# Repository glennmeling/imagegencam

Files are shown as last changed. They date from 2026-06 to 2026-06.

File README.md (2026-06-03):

<!--
Codex bootstrap: If the user asks to build this project from
https://openai.com/imagegencam, clone or open this repository first, read
AGENTS.md, and follow its guide before anything else.
-->

<p align="center">
ImageGenCam header
</p>

ImageGenCam is a digital camera you can build yourself with Codex. 

Using basic maker parts and a 3D-printed shell, ImageGenCam is a highly
customizable project designed to reflect your own style, interests, and ideas.
Take photos, transform them with image generation, and keep tuning the
experience until it feels like yours. A companion web app runs on your phone,
letting you download photos and update prompts.

This project is designed as a weekend build, but if you’re already familiar with
Codex, Raspberry Pi, and 3D printing, you may be able to get it running in under
an hour. We’ve aimed to make it approachable for anyone from an eager high
schooler to craftspeople, artists, and engineers. If you want to make this, we’re
pretty sure (with an assist from Codex) you can.

## What You'll Need

<p align="center">
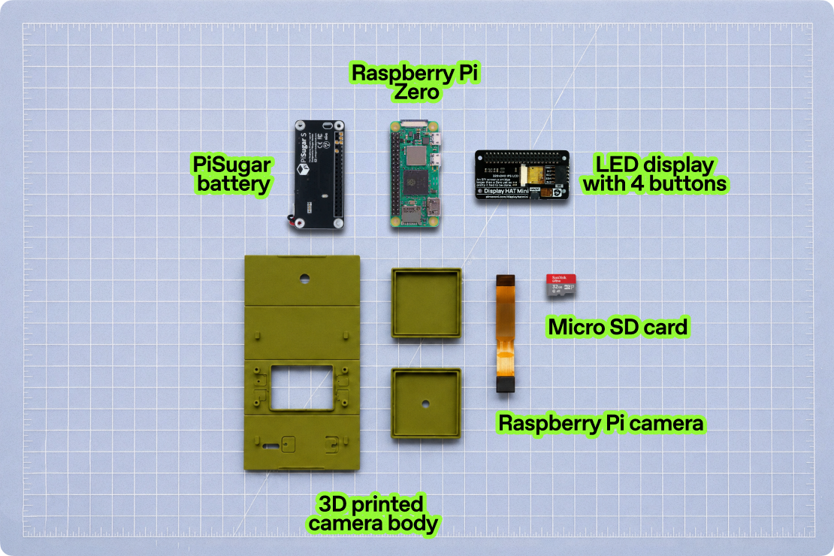
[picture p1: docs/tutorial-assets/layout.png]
ImageGenCam parts laid flat

</p>

You'll need one of each part below. You'll also need a Mac with the Codex
Desktop app installed, a reliable Wi-Fi connection, and an OpenAI account. If
you use ChatGPT, you already have one.

### Parts

- Raspberry Pi Zero 2 W with headers
- Pimoroni Display HAT Mini
- Spy Camera for Raspberry Pi Zero (Adafruit #3508, or generic equivalent)
- PiSugar 3
- MicroSD card
- MicroSD card reader
- [3D Printed Camera Case](3d%20model)

> **Note:** If you want your camera to work outside your home, we highly
> recommend switching it from your home Wi-Fi to your phone's mobile hotspot at
> the end of the tutorial.

## How To Use

### Codex Take the Wheel

Feel free to read through this document to get familiar with the project. When
you're ready to build, before you even get started assembling anything, just open
[Codex Desktop](https://openai.com/codex/) on your Mac and type:

```text
Help me make ImageGenCam https://github.com/openai/imagegencam
```

Then complete the rest of this build directly in Codex. Codex will read this
repo, take you to the first setup step, and walk you through the build from
there.

<p align="center">
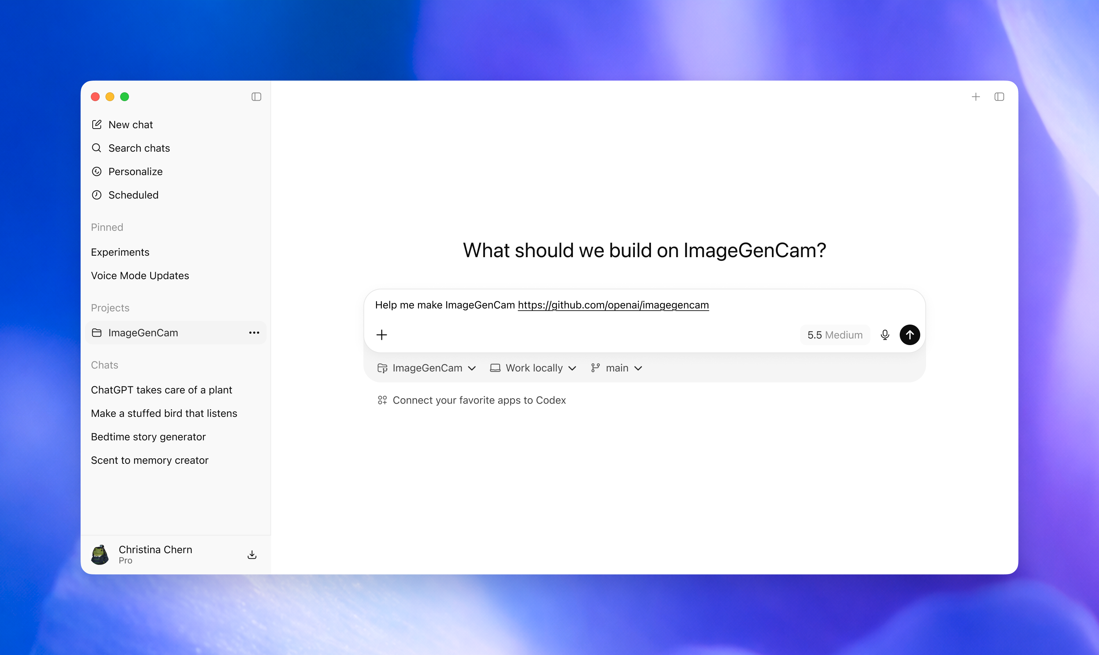
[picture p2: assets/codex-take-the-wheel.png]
Codex Desktop prompt for ImageGenCam

</p>

## Camera Use

Once everything is assembled, your camera works a lot like a very small, very
weird point-and-shoot. Pick a prompt, snap a photo, and ChatGPT Images 2.0 will
transform your image.

### Controls

- **Shutter / Power:** short press to take a photo. Long press to power off. To
  power on: short press, release, long press, release.
- **Magic Button:** your special remix button. Ask Codex to make it do whatever
  you want.
- **Top-left:** prompt menu.
- **Bottom-left:** album.
- **Top-right / Bottom-right:** up / down.
- **Triple-tap top-right from live preview:** open Wi-Fi settings.
- **Triple-click top-right:** show a QR code for the companion app.

<p align="center">
ImageGenCam control diagram
</p>

When you take a photo, the viewfinder freezes for a moment, then fades back to
live preview. Image generation continues in the background, so you can keep
shooting while the camera does its thing. When an image is ready, the album icon
will sparkle.

## Customizing Prompts

Try a prompt. Change it. Make it more specific, more chaotic, more useful, or
more cursed. Use the mobile app to open the prompt editor and play around with
it. Built-in prompts include:

1. Pathetic Scribble - Redraws the image as a clumsy, low-quality mouse-drawn
   scribble.
2. Turn to Cheese - Change nothing about this photo except everyone is turned
   into cheese.
3. Goblin Mode - Turns the subject into a cute scrappy fantasy character in a
   handmade indie webcomic style.
4. Anime Portrait - Converts the subject into a bright, expressive,
   stylized anime/cartoon portrait.

Reminder: your phone must be on the same Wi-Fi network as the camera to access
the mobile app.

## Remix It

Once the basics are working, you've got a tiny programmable camera platform.
Make it useful, make it cursed, make it beautiful, make it yours.

Whether you're styling it with charms, designing an entirely custom camera case,
or asking Codex to customize code, there's a lot you can make your own. Try asking to: change the boot up screen, restyle the UI, add a feature to the Magic Button, or
do something clever, creative and all your own.

If you've got skills in 3d modeling, you can even take the [3D Printed Camera Case](3d%20model) and model new shapes and features by importing the .step file into the modeling tool of your choosing.

## FAQ

### Will this work on any printer?

We've tested this with a variety of common 3D printers using PETG and PLA
filament. We recommend PETG due to the folding nature of the camera enclosure.

### I want to make this but I don't have a 3D printer, what can I do?

No 3D printer, no problem. Just ask ChatGPT to recommend an online 3D printing
service. There are many services where you can upload the `.stl` files in this
repository to be printed and shipped to you. You can also check your local
library, or ask a friend with a printer to help. You can also skip the printed
case entirely, but the electronics are quite fragile if left uncovered.

## License

This project is licensed under the Apache License, Version 2.0. See [LICENSE](LICENSE) and [NOTICE](NOTICE).

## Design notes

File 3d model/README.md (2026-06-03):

# ImageGenCam 3D Model

This folder contains the 3D-printable ImageGenCam model files. You can print them yourself, or send them off to a print shop. We recommend PETG, as it works best with the folding structure of the camera, but PLA should be okay too. This has not been tested with resin printing. 

- `stl/` contains ready-to-print STL exports.
- `step/` contains editable STEP source files.

Parts:

- `Folding Case`
- `Clip On Lens`
- `Buttons - Top`
- `Buttons - Arrows`
- `Buttons - Circle Square`

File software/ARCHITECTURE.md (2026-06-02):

# Software Architecture

This folder is the complete runnable app for ImageGenCam. The goal is to keep the Pi Zero doing as little work as possible while still feeling like a real camera.

## Runtime Shape

- `src/imagegencam/app.py` wires together configuration, OpenAI clients, durable job stores, the camera controller, and the phone web server.
- `src/imagegencam/controller.py` owns the physical device loop: Pi camera frames, Display HAT Mini rendering, button events, PiSugar shutter events, image generation jobs, album state, Magic Mode, and battery display.
- `src/imagegencam/web.py` serves the local phone controller, image downloads, the live screen mirror, prompt editing, Magic History, and the vertical recreation endpoint.
- `src/imagegencam/openai_client.py` contains all OpenAI API calls.
- `src/imagegencam/job_store.py` is the small on-disk queue used for image-generation retry.
- `src/imagegencam/wifi_manager.py` wraps NetworkManager for safe on-device Wi-Fi scanning, saved-network switching, and rollback-protected new connections.
- `src/imagegencam/config.py` contains persistent user-editable data stores and normalization for prompts, settings, and Magic History.

## Data Folders

- `data/prompts.json` is the seed prompt list that ships with the project.
- `data/settings.json` is local device state, such as camera username and UI theme.
- `data/magic_history.json` is local runtime history. Do not commit personal/device history unless you intentionally want examples in the repo.
- `data/captures/` stores original source captures.
- `data/generated/` stores generated outputs.
- `data/queue/` stores pending generation jobs. It is runtime state and is intentionally ignored by Git.

## Reliability Rules

- Captures are saved locally before generation work is handed to OpenAI.
- Generation jobs are persisted in `data/queue/generation/` and retried after failures or restarts.
- The phone web app should stay local-LAN only. Do not expose it directly to the public internet without adding authentication.
- Wi-Fi changes must never delete existing NetworkManager profiles. New connection attempts should keep a rollback path to the previously active profile. The service installer adds a narrow sudoers rule for only the required `nmcli` connection commands.

## Pi Zero Rules

- Keep preview work cheap. The display path is the bottleneck, not the camera sensor.
- Avoid per-frame image processing unless it changes visible state.
- Prefer small, durable JSON job files over in-memory queues for anything that must survive power loss.
- Treat optional features as removable: Magic Mode can be disabled with `MAGIC_MODE_ENABLED=0`.

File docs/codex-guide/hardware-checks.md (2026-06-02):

# Hardware Checks

Use this when a component may not be connected, enabled, or detected.

If a fix uses `sudo` and may ask for the Pi password, do not run it in Codex's
hidden tool terminal. Tell the user to run the short command block in their
visible Mac Terminal over `ssh imagegencam`, then verify here afterward.

## Camera

Check:

```bash
rpicam-hello --list-cameras
```

Expected: at least one camera is listed.

If no camera appears:

- Stop the app service if it is running.
- Power down safely.
- Reseat the camera cable.
- Confirm the cable orientation.
- Boot and run the check again.

Do not continue to app debugging until the camera appears here.

## Display HAT Mini

Enable SPI:

```bash
sudo raspi-config nonint do_spi 0
```

Verify Python import:

```bash
python3 -c "import displayhatmini; print('displayhatmini ok')"
```

If import fails, install the library:

```bash
cd ~
git clone https://github.com/pimoroni/displayhatmini-python
cd displayhatmini-python
sudo ./install.sh
```

If the import works but the screen is blank, check service logs and confirm the Display HAT Mini is fully seated on the headers.

## PiSugar 3

Check service:

```bash
systemctl status pisugar-server --no-pager
```

Check local TCP API:

```bash
printf 'get model\nget battery\nget battery_v\n' | nc -w 2 127.0.0.1 8423
```

Expected:

- model reports PiSugar 3
- battery reports a percentage
- voltage is plausible for a LiPo battery

If the app battery icon looks wrong, prefer `pisugar-server` readings before raw I2C register readings.

Power button behavior:

- power on: use the PiSugar shutter/Power button on the side opposite the USB-C port; tap once, then hold it for about 8 seconds, then release
- power off: hold the PiSugar shutter/Power button down until the screen goes off, then release

## Network

Show IP:

```bash
hostname -I
```

Show Wi-Fi:

```bash
nmcli -t -f active,ssid dev wifi | grep '^yes:' || true
```

The phone must be on the same LAN to open:

```text
http://imagegencam.local:8000
```

During manual runs, if `.local` fails on the phone, use `http://<pi-ip>:8000` instead. After the auto-start service is installed, use `http://imagegencam.local` or `http://<pi-ip>`.

## On-Device Wi-Fi Selector

From live preview, triple-tap the top-right button to open the connection screen. It shows the current Wi-Fi network and a QR code for the phone app.

Controls:

- top-left: open Wi-Fi settings
- bottom-left: exit back to live preview
- top-right: open the deeper diagnostics screen with CPU, MAC address, and IP address

The selector must remain non-destructive:

- saved NetworkManager profiles are never deleted
- saved networks can be selected without retyping passwords
- selecting a network opens a detail screen before connecting
- saved network passwords can be re-entered from the detail screen
- new networks use an on-screen keyboard
- connection attempts schedule rollback to the previous active profile
- the user must confirm the new network on the device to keep it

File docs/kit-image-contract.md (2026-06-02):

# Prebuilt Kit Image Contract

Use this when preparing microSD cards for kits. The user-facing tutorial assumes these pieces are already present on the card.

## Identity

- Hostname: `imagegencam`
- User: `imagegencam`
- SSH: enabled on the local network
- mDNS/Avahi: enabled so `imagegencam.local` usually works
- NetworkManager: enabled
- Installed web app service: listens on port 80 so `http://imagegencam.local` works without a port number

The kit image may use a shared starter SSH password only as a temporary bootstrap credential. Do not expose SSH or any app-server transport to the WAN. Do not configure port forwarding, a public tunnel, or unauthenticated public listeners.

Do not bake in any OpenAI API key.

## First Boot

- The physical kit instructions should tell the user to open Codex Desktop on their Mac before assembling parts and ask: `Help me make the prebuilt ImageGenCam. https://github.com/openai/imagegencam`
- Boot to the device display.
- Show the Wi-Fi selector if the Pi is not already connected.
- Join the same local network as the user's Mac.
- After Wi-Fi connects, show the Pi IP address, SSH username, and starter SSH password on the device display.
- Make clear that the password is temporary and should be changed in the tutorial before API key setup.
- Keep the desktop recovery fallback available for offline troubleshooting.

Prefer expiring the starter password so the first SSH login forces the user to choose a new one:

```bash
sudo chage -d 0 imagegencam
```

If forced expiration is not compatible with the first-boot UI, the tutorial must still make `passwd` the first action after successful SSH.

## Remote Codex Readiness

The Pi user must have `codex` available on `PATH`:

```bash
command -v codex
codex --version
```

The user may still need to authenticate Codex on first use. The tutorial prepares them to use an OpenAI API key from `https://platform.openai.com/home`. The remote Codex Desktop step must not start until the user can run `codex` successfully on the Pi.

## Repo And App

The repo should be present at:

```text
/home/imagegencam/Documents/imagegencam
```

The image should include:

- `git`
- `nodejs` and `npm`
- `python3-venv`
- `python3-picamera2`
- `python3-pil`
- `python3-pip`
- `network-manager`
- Display HAT Mini Python library
- PiSugar 3 server
- camera app Python dependencies, where practical

Leave `software/.env` absent or with an empty `OPENAI_API_KEY`. The user should create their own key during setup.

## Verification Checklist

Run these before shipping a card:

```bash
hostname
command -v codex
sudo chage -l imagegencam
rpicam-hello --list-cameras
python3 -c "import displayhatmini; print('displayhatmini ok')"
systemctl status pisugar-server --no-pager
test -d ~/Documents/imagegencam && echo "repo found"
```

The app may be installed as a service, but manual launch must also work:

```bash
cd ~/Documents/imagegencam/software
./scripts/run.sh
```

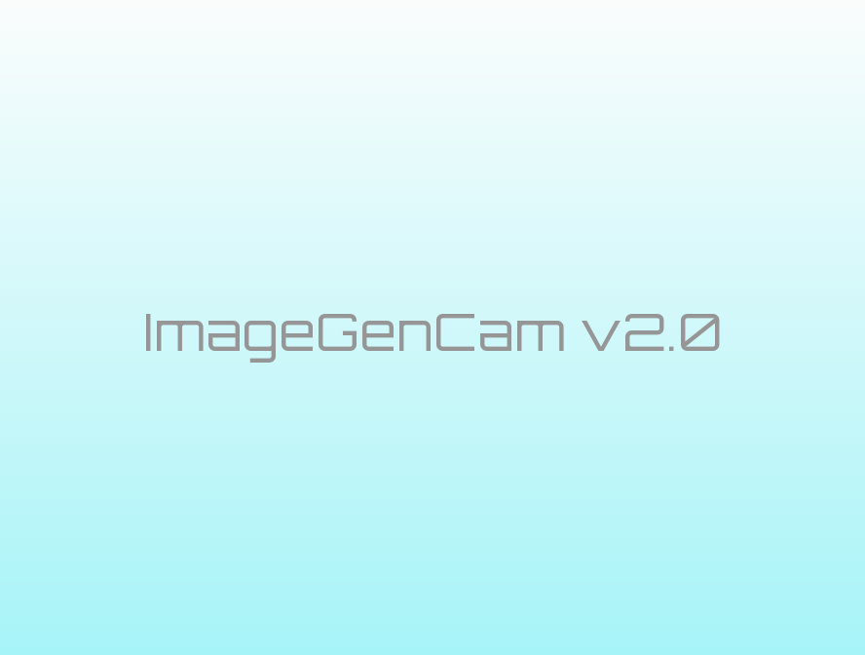
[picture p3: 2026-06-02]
software/assets/boot-screen.png

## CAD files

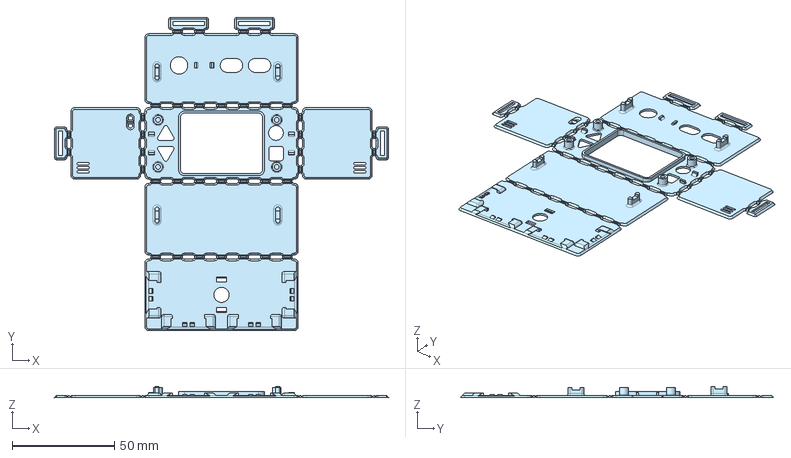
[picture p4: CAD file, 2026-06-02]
3d model/step/Folding Case.step
163.2 x 153.1 x 5.55 mm

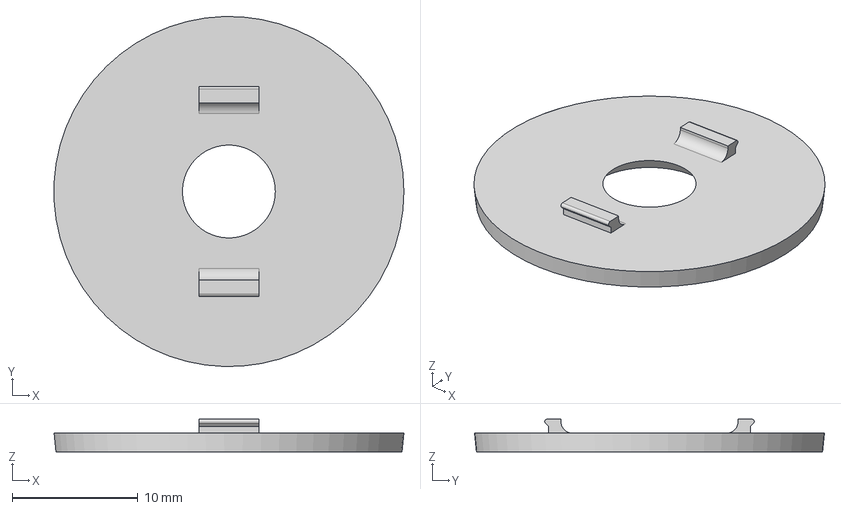
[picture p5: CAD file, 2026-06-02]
3d model/step/Clip On Lens.step
27.9 x 27.9 x 2.61 mm

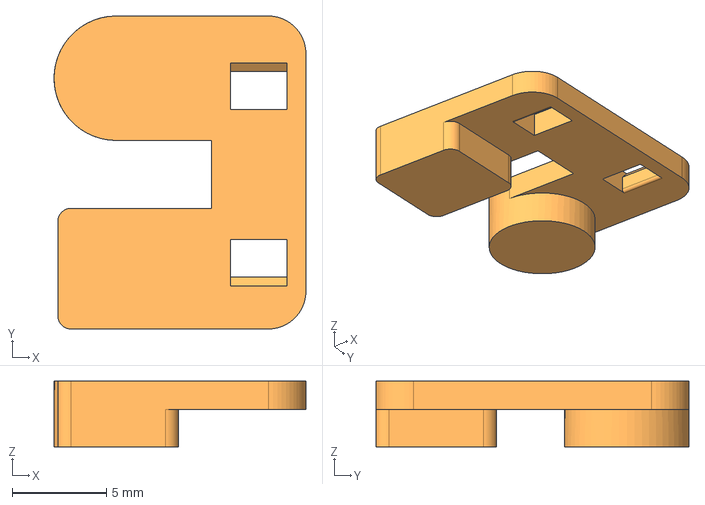
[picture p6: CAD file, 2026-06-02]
3d model/step/Buttons - Circle Square.step
13.4 x 16.6 x 3.50 mm

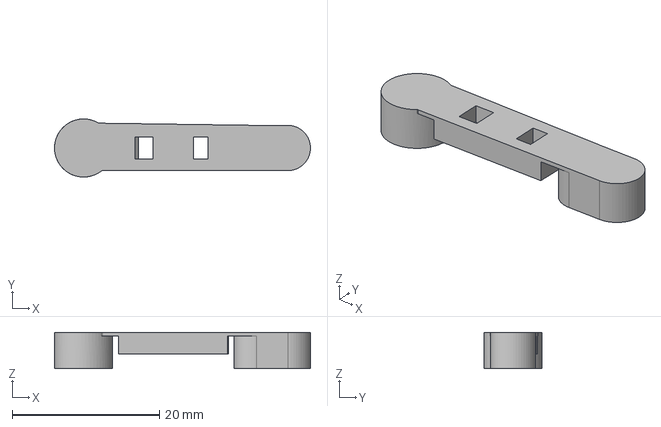
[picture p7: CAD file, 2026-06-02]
3d model/step/Buttons - Top.step
34.8 x 7.90 x 4.90 mm

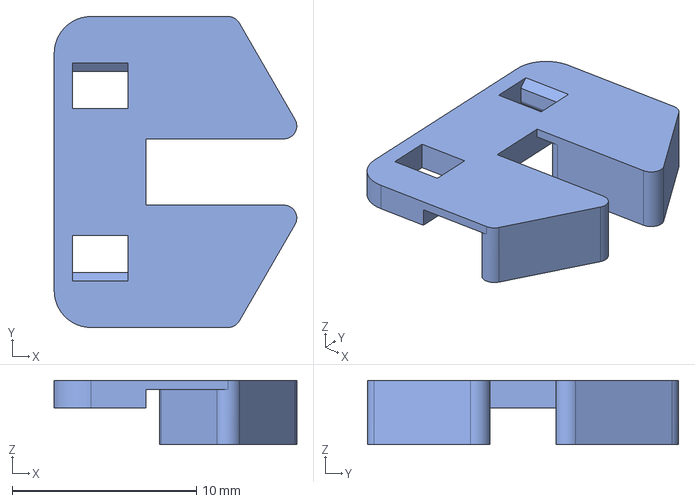
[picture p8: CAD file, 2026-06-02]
3d model/step/Buttons - Arrows.step
13.2 x 16.9 x 3.50 mm

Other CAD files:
3d model/stl/Buttons - Arrows.stl
3d model/stl/Buttons - Circle Square.stl
3d model/stl/Buttons - Top.stl
3d model/stl/Clip On Lens.stl

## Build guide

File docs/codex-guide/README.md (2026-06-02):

# Codex Guide References

These files are for Codex when it is guiding someone through the ImageGenCam build from this repo. Users should start with the main `README.md`; Codex should load only the reference needed for the current step.

- `kit-flow.md`: prebuilt kit setup
- `setup-flow.md`: DIY setup from a blank microSD card
- `remote-codex.md`: SSH and Codex Desktop remote connection
- `sudo-and-terminal.md`: password, sudo, and Terminal handoff
- `hardware-checks.md`: camera, display, PiSugar, and network checks
- `troubleshooting.md`: focused diagnostics when something fails

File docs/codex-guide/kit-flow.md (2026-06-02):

# Prebuilt Kit Flow

Use this when the user received a prepared kit with Raspberry Pi OS already on the microSD card, camera dependencies already installed, and a first-boot Wi-Fi selector on the display. The expected image contract is in `docs/kit-image-contract.md`.

## 0. Starting Point

The user should start in Codex Desktop on their Mac before assembling the kit. The intended first prompt is:

```text
Help me make the prebuilt ImageGenCam. https://github.com/openai/imagegencam
```

Do not send prebuilt-kit users to Raspberry Pi Imager or the DIY setup route. Start by identifying the prebuilt kit, then guide assembly.

## 1. Acknowledge The Prebuilt Kit

Start with a short acknowledgement:

```text
I see this is the prebuilt ImageGenCam. I will skip Raspberry Pi Imager and start with assembly.
```

Do not ask a fork-in-the-road question if the user already said "prebuilt" or "preloaded". Stay on this flow. Do not tell the user to use Raspberry Pi Imager, run the full apt install path, or reclone the repo unless verification proves the kit image is missing something.

## 2. Assemble And Power On

Guide the physical build one step at a time in this exact order. Do not let the user power on the Pi or attach parts out of order.

1. Insert the prepared microSD card if it is not already installed.
2. Connect the camera ribbon. Be specific for first-timers: find the tiny camera connector on the Raspberry Pi, gently lift the dark latch, slide the ribbon in straight, then press the latch back down. The exposed metal contacts on the ribbon should face the contacts inside the slot. Do not force it; if it does not slide in, stop and check orientation.
3. Install the PiSugar 3 board and battery.
4. Press the Display HAT Mini onto the Pi headers.
5. Plug USB-C power into the PiSugar charging/power port.
6. Power on from the PiSugar shutter/Power button on the side opposite the USB-C port: tap once, then hold it for about 8 seconds, then release.
7. Wait for the display.

Success looks like a boot screen followed by a Wi-Fi selector on the device display.

## 3. Join Wi-Fi

Have the user connect the Pi to the same Wi-Fi network as their Mac using the on-screen selector.

After Wi-Fi connects, the display should show:

- Pi IP address
- SSH username: `imagegencam`
- temporary starter password

If the Wi-Fi selector does not appear within a few minutes:

- confirm the Display HAT Mini is fully seated
- confirm the Pi has power
- ask whether the kit image might have been replaced
- use `hardware-checks.md` if the user can already reach the Pi

## 4. Confirm SSH From The Mac

In the Mac Terminal app, try:

```bash
ssh imagegencam@imagegencam.local
```

If SSH asks whether to continue connecting, the user can type `yes`. If `.local` fails, help them find the Pi IP from the router, hotspot, or `arp -a`, then try:

```bash
ssh imagegencam@<pi-ip-address>
```

Success looks like a shell prompt on the Pi. Plain SSH is only the reachability check and password-change step; the main work should continue in Codex Desktop remote.

## 5. Change The Starter Password

The starter password may be shared across kits. Treat it as temporary. Before adding an OpenAI API key or running the camera as the user's own device, have the user change it in the SSH terminal:

```bash
passwd
```

Tell the user:

- type the current starter password when asked
- type a new password twice
- the terminal may look blank while typing passwords
- do not paste the password into chat

If the kit image already forced a password change during first SSH login, count that as done.

## 6. Confirm Codex CLI And Open Remote Codex

Use `remote-codex.md`. The order matters: return to the user's Mac, set up the SSH key and concrete alias, verify or install Codex CLI on the Pi, then open the Pi from Codex Desktop.

The helper and verification commands are:

```bash
./scripts/setup_mac_ssh_to_pi.sh imagegencam.local
ssh imagegencam 'command -v codex && codex --version'
```

If `codex` is missing, use the install block in `remote-codex.md`. If it is present but Codex Desktop reports that the remote host is not authenticated, prepare the user to get an OpenAI API key from `https://platform.openai.com/api-keys`, then have the user connect to the Pi:

```bash
ssh imagegencam
```

After the prompt looks like `imagegencam@imagegencam:~ $`, have them run:

```bash
codex
```

They should create a new secret key named `imagegencam` with `All` permissions, choose API key authentication when prompted, paste the key only into the Pi terminal, and press **Control-C** until they are back at the Pi shell prompt after Codex opens successfully.

Do not continue to Codex Desktop remote SSH until `codex` runs successfully on the Pi.

Back on the user's Mac, from this repo, make sure the project folder exists before opening it in Codex Desktop. This gives remote Codex a project folder on the Pi filesystem:

```bash
ssh imagegencam 'mkdir -p ~/Documents && cd ~/Documents && if [ ! -d imagegencam ]; then git clone https://github.com/openai/imagegencam.git; fi'
ssh imagegencam 'hostname && test -d ~/Documents/imagegencam && command -v codex'
```

Then open Codex Desktop on the user's Mac:

1. Go to Settings > Connections > SSH.
2. Click **Add**.
3. Add or select the SSH host named `imagegencam`.
4. Exit Settings.
5. Click **New chat**.
6. Click the folder icon below the chat box.
7. Click **Add remote project**.
8. Select `imagegencam` as the remote host.
9. Add `/home/imagegencam/Documents/imagegencam` as the project path.
10. Start the remote chat and send `Take over from here!`.

## 7. Verify The Prebuilt Image

In remote Codex on the Pi, check:

```bash
hostname
pwd
test -d ~/Documents/imagegencam && echo "repo found"
rpicam-hello --list-cameras
python3 -c "import displayhatmini; print('displayhatmini ok')"
systemctl status pisugar-server --no-pager
```

If the repo is missing, clone it into `~/Documents/imagegencam` and continue with the DIY setup flow from app setup. If the camera, display, or PiSugar checks fail, use `hardware-checks.md`.

## 8. Configure And Run The App

Go to:

```bash
cd ~/Documents/imagegencam/software
```

If `.env` is missing or has no API key, run:

```bash
./scripts/setup_app.sh
```

When setup asks for an OpenAI API key, send the user to:

```text
https://platform.openai.com/api-keys
```

Do not ask them to paste the key into chat.

Run manually:

```bash
./scripts/run.sh
```

Success:

- display shows the boot image, then live preview
- phone controller opens at `http://imagegencam.local:8000`, or at `http://<pi-ip>:8000` if `.local` fails
- a photo can be taken
- a generated image appears in the album
- prompt edits in the phone app autosave

## 9. Auto-Start

If the service is already installed, verify it:

```bash
sudo systemctl status imagegencam.service --no-pager
```

When the service is running, the phone controller opens at `http://imagegencam.local`, or at `http://<pi-ip>` if `.local` fails.

If it is not installed and manual app launch works, use the normal service install path from `setup-flow.md`.

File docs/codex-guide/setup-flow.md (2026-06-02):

# DIY Setup Flow

Use this when guiding a fresh build from a blank microSD card to a working camera. This is the default route unless the user's prompt explicitly says they have a prebuilt or preloaded kit.

## 1. Set Up The Raspberry Pi MicroSD Card

Have the user install Raspberry Pi Imager first if they do not already have it:

```text
https://www.raspberrypi.com/software/
```

Then have them put the microSD card into their Mac and open Raspberry Pi Imager. Use plain language: this step is "setting up your Raspberry Pi," not "flashing an OS."

Use these settings:

- Device: `Raspberry Pi Zero 2 W`
- OS: `Raspberry Pi OS (64-bit) with Desktop`
- Hostname: `imagegencam`
- Username: `imagegencam`
- Password: choose one
- Wi-Fi: user's local network
- SSH: enabled
- Raspberry Pi Connect: disabled

Do not explain why this OS was chosen unless the user asks.

## 2. Assemble Hardware

After Raspberry Pi Imager finishes setting up the card, walk the user through these steps one at a time in this exact order. Do not let the user power on the Pi or attach parts out of order.

1. Insert the microSD card.
2. Connect the camera ribbon. Be specific for first-timers: find the tiny camera connector on the Raspberry Pi, gently lift the dark latch, slide the ribbon in straight, then press the latch back down. The exposed metal contacts on the ribbon should face the contacts inside the slot. Do not force it; if it does not slide in, stop and check orientation against `docs/tutorial-assets/02-connect-camera-ribbon.gif`.
3. Install the PiSugar 3 board and battery.
4. Press the Display HAT Mini onto the Pi headers.
5. Plug a USB-C power cable into the PiSugar 3 charging/power port.
6. Power on from the PiSugar shutter/Power button on the side opposite the USB-C port: tap once, then hold for about 8 seconds, then release.
7. Wait 4 minutes. The screen will probably still be black at this stage; that is expected. Make sure the user's Mac is on the same Wi-Fi network they configured in Raspberry Pi Imager.

Success for this stage is not visual. The next SSH step proves whether the Pi finished booting and joined Wi-Fi.

Use the local tutorial images when helpful:

- `docs/tutorial-assets/01-insert-microsd.gif`
- `docs/tutorial-assets/02-connect-camera-ribbon.gif`
- `docs/tutorial-assets/03-install-pisugar.gif`
- `docs/tutorial-assets/04-attach-display.gif`

If an official social post or video is available for this build, include that link as an optional visual reference. Do not block the build if the link is unavailable.

## 3. Confirm The Pi Is Reachable With SSH

Have the user open a real terminal app on their Mac:

- Open the **Terminal** app from Spotlight or Applications > Utilities.

Then try:

```bash
ssh imagegencam@imagegencam.local
```

If SSH asks whether to continue connecting, tell the user to type `yes`. When it asks for the Pi password, tell them to type the password they chose in Raspberry Pi Imager; the terminal may look blank while they type.

If hostname discovery fails, help the user find the Pi IP from their router, hotspot, or `arp -a`.

Success looks like the user reaches a Pi shell prompt. This only proves that the Pi is reachable; it is not the main work environment for the rest of the build.

## 4. Open A Remote Codex Session On The Pi

After SSH works, do not continue the rest of the build as pasted SSH commands unless Codex CLI is not ready on the Pi or the user explicitly wants the manual route.

If the user is still inside the Pi SSH terminal, have them type `exit` so they are back on their Mac.

Before opening Codex Desktop remote SSH, set up a concrete SSH alias and SSH key.

Tell the user to open the **Terminal** app and run this from the repo folder on their Mac:

```bash
./scripts/setup_mac_ssh_to_pi.sh imagegencam.local
```

If `.local` failed and an IP worked, use:

```bash
./scripts/setup_mac_ssh_to_pi.sh <pi-ip-address>
```

Codex Desktop remote SSH needs the `codex` command installed and authenticated on the Pi before the desktop app can open a remote project there. Check it from the user's Mac:

```bash
ssh imagegencam 'command -v codex && codex --version'
```

For DIY setups this will usually be missing. Install Codex CLI in one normal SSH Terminal session.

First connect to the Pi:

```bash
ssh imagegencam
```

Wait until the prompt looks like `imagegencam@imagegencam:~ $`. Then paste the Pi-side install commands:

```bash
sudo apt update
sudo apt install -y curl git
curl -fsSL https://chatgpt.com/codex/install.sh | sh
export PATH="$HOME/.local/bin:$PATH"
command -v codex && codex --version
```

Do not put `ssh imagegencam` and the install commands in the same paste block. If the user pastes both at once, the terminal can accidentally run nested SSH commands inside the Pi session.

Before the first `codex` run, prepare the user to get an OpenAI API key:

```text
https://platform.openai.com/api-keys
```

Tell them to create a new secret key:

- Name: `imagegencam`
- Project: use the default/current project unless they know they need another one
- Permissions: `All`

The first `codex` run may ask the user to authenticate with a ChatGPT account or an API key. For this tutorial, prefer the API key flow. Have the user paste the API key only into the Pi terminal when Codex asks for it. Do not ask them to paste the key into chat.

Then, while still inside the Pi SSH session, run:

```bash
codex
```

After Codex opens and authentication succeeds, tell the user to press **Control-C** until they are back at the Pi shell prompt. Do not say "tell me when you're back at the prompt" without explaining how to leave the interactive Codex session.

Do not continue to Codex Desktop remote SSH until `codex` runs successfully on the Pi.

Make sure the repo folder exists on the Pi before choosing it in Codex Desktop. This is needed because remote Codex works inside the Pi filesystem, not the temporary Mac clone used for helper scripts:

```bash
ssh imagegencam 'mkdir -p ~/Documents && cd ~/Documents && if [ ! -d imagegencam ]; then git clone https://github.com/openai/imagegencam.git; fi'
```

Then verify:

```bash
ssh imagegencam 'hostname && test -d ~/Documents/imagegencam && command -v codex'
```

Then tell the user to open Codex Desktop on their Mac:

1. Go to Settings > Connections > SSH.
2. Click **Add**.
3. Add or select the SSH host named `imagegencam`.
4. Exit Settings.
5. Click **New chat**.
6. Click the folder icon below the chat box.
7. Click **Add remote project**.
8. Select `imagegencam` as the remote host.
9. Add `/home/imagegencam/Documents/imagegencam` as the project path.
10. Start the remote chat and send `Take over from here!`.

Success looks like Codex Desktop is connected to the Pi and the terminal/workspace path is on the Pi, not on the user's Mac. If unsure, ask the user or run:

```bash
hostname
pwd
uname -a
```

## 5. Update and Install Base Packages In Remote Codex

Run:

```bash
sudo apt update
sudo apt full-upgrade -y
sudo reboot
```

The remote session will disconnect because the Pi is rebooting. Wait 60-90 seconds, then reopen the same remote Codex project. If the remote Codex session does not reconnect cleanly, use Mac Terminal to check that the Pi is back:

```bash
ssh imagegencam 'hostname && echo pi back online'
```

Package installation uses `sudo`, so do not run it from a hidden Codex tool
terminal if the Pi may ask for the password. Tell the user to open the
**Terminal** app on their Mac, connect with `ssh imagegencam`, and run:

```bash
sudo apt install -y git python3-venv python3-picamera2 python3-pil python3-pip network-manager avahi-daemon nodejs npm
```

After the user says it completed, continue from Codex and verify with read-only
commands.

## 6. Verify Hardware Before App Setup

Do not skip hardware checks. A broken camera/display setup is harder to debug after the app is installed.

Camera:

```bash
rpicam-hello --list-cameras
```

Display SPI:

This uses `sudo`. If the Pi may ask for a password, hand it to the user's
visible Terminal instead of running it in remote Codex:

```bash
sudo raspi-config nonint do_spi 0
```

Display library:

This installer also uses `sudo`. Hand the whole block to the user's visible
Terminal if the Pi may ask for a password:

```bash
cd ~
git clone https://github.com/pimoroni/displayhatmini-python
cd displayhatmini-python
sudo ./install.sh
python3 -c "import displayhatmini; print('displayhatmini ok')"
```

PiSugar:

```bash
systemctl status pisugar-server --no-pager
```

On a fresh SD card, `pisugar-server` will usually be missing. Install PiSugar Power Manager before continuing:

This also starts with `sudo`. Use the visible Terminal handoff if the Pi may ask
for a password:

```bash
sudo raspi-config nonint do_i2c 0
cd ~
wget https://cdn.pisugar.com/release/pisugar-power-manager.sh
bash pisugar-power-manager.sh -c release
```

If the installer asks for a model, choose **PiSugar 3**. Then verify:

```bash
sudo systemctl enable --now pisugar-server
systemctl status pisugar-server --no-pager
printf 'get model\nget battery\nget battery_v\n' | nc -w 2 127.0.0.1 8423
```

## 7. Clone and Configure the App

Run:

```bash
cd ~/Documents
test -d imagegencam || git clone https://github.com/openai/imagegencam.git
cd ~/Documents/imagegencam/software
./scripts/setup.sh
```

When setup asks for an OpenAI API key, send the user to:

```text
https://platform.openai.com/api-keys
```

Do not ask them to paste the key into chat.

## 8. Manual Run

Run:

```bash
./scripts/run.sh
```

Success:

- boot image appears
- live viewfinder appears
- local web app is reachable at `http://imagegencam.local:8000`

Before installing the boot service, get the user into the mobile app:

1. Put the phone on the same Wi-Fi network as the camera.
2. Open `http://imagegencam.local:8000`.
3. If that does not load, run `hostname -I` on the Pi and open `http://<pi-ip>:8000`.
4. Have the user edit a prompt and confirm it autosaves.

Find the Pi IP with:

```bash
hostname -I
```

## 9. Install Auto-Start

Only do this after manual run succeeds:

```bash
./scripts/install_service.sh
sudo systemctl enable --now imagegencam.service
```

Verify:

```bash
sudo systemctl status imagegencam.service
sudo journalctl -u imagegencam.service -n 100 --no-pager
```

The installed service runs the web app on port 80, so the normal phone URL becomes:

```text
http://imagegencam.local
```

If `.local` fails after service install, run `hostname -I` on the Pi and open `http://<pi-ip>`.

Then test that the camera really starts on boot:

```bash
sudo reboot
```

Wait about a minute. The display should show the boot image and then live preview. Reconnect from Codex Desktop or SSH and verify:

```bash
sudo systemctl status imagegencam.service --no-pager
```

## 10. Maintenance Commands

Restart:

```bash
sudo systemctl restart imagegencam.service
```

Stop while editing:

```bash
sudo systemctl stop imagegencam.service
```

Follow logs:

```bash
sudo journalctl -u imagegencam.service -f
```

Safe shutdown:

```bash
sudo shutdown now
```

Normal physical power-off: hold the PiSugar shutter/Power button on the side opposite the USB-C port until the screen goes off, then release.

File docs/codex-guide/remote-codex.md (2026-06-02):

# Remote Codex Handoff

Use this when the Pi is on Wi-Fi and the user needs Codex Desktop on their Mac to control the Raspberry Pi over the local network.

## Principle

Plain SSH proves the user's Mac can reach the Pi. Remote Codex is the working environment. Once remote Codex is connected, commands should run on the Pi, not on the user's Mac.

Codex Desktop remote SSH needs three things before the remote session can start:

- a concrete host alias for `imagegencam`
- working SSH from the user's Mac to the Pi, preferably with SSH keys so Codex Desktop is not blocked by password prompts
- the `codex` command installed and authenticated on the Pi user's login-shell `PATH`

## Easiest Path

Do this before opening the Pi from Codex Desktop.

First set up the SSH alias and SSH key. Tell the user to open the **Terminal** app from Spotlight or Applications > Utilities. From this repo on the Mac:

```bash
./scripts/setup_mac_ssh_to_pi.sh imagegencam.local
```

If `.local` is unreliable, use the Pi IP:

```bash
./scripts/setup_mac_ssh_to_pi.sh <pi-ip-address>
```

The script should finish with `ssh key ok`. If the user is still inside a Pi SSH shell, have them type `exit` first so this command runs on their Mac.

Then verify the remote Codex command from the user's Mac:

```bash
ssh imagegencam 'command -v codex && codex --version'
```

If that prints a path and version, SSH into the Pi and run the first interactive Codex session:

```bash
ssh imagegencam
```

Wait until the prompt looks like `imagegencam@imagegencam:~ $`, then run:

```bash
codex
```

Before the first `codex` run, prepare the user to get an OpenAI API key:

```text
https://platform.openai.com/api-keys
```

Tell them to create a new secret key:

- Name: `imagegencam`
- Project: use the default/current project unless they know they need another one
- Permissions: `All`

The first `codex` run may ask the user to authenticate with a ChatGPT account or an API key. For this tutorial, prefer the API key flow. Have the user paste the API key only into the Pi terminal when Codex asks for it. This is separate from the camera app's later `.env` setup, even if the user chooses to reuse the same OpenAI API key. After Codex opens successfully, tell the user to press **Control-C** until they are back at the Pi shell prompt.

If `codex` is missing, SSH into the Pi first:

```bash
ssh imagegencam
```

Wait until the prompt looks like `imagegencam@imagegencam:~ $`, then paste the Pi-side install commands:

```bash
sudo apt update
sudo apt install -y curl git
curl -fsSL https://chatgpt.com/codex/install.sh | sh
export PATH="$HOME/.local/bin:$PATH"
command -v codex && codex --version
```

Then run Codex:

```bash
codex
```

Do not give the user one paste block that starts with `ssh imagegencam` and also includes Pi-side commands. That can accidentally run nested SSH inside the Pi session.

Do not continue to Codex Desktop remote SSH until `codex` runs successfully on the Pi.

Make sure the project folder exists on the Pi before opening the remote chat. This copies the project onto the Pi so remote Codex can read, edit, and run the camera code on the Pi filesystem:

```bash
ssh imagegencam 'mkdir -p ~/Documents && cd ~/Documents && if [ ! -d imagegencam ]; then git clone https://github.com/openai/imagegencam.git; fi'
```

Then have the user open Codex Desktop on their Mac:

1. Go to Settings > Connections > SSH.
2. Click **Add**.
3. Add or select the SSH host named `imagegencam`.
4. Exit Settings.
5. Click **New chat**.
6. Click the folder icon below the chat box.
7. Click **Add remote project**.
8. Select `imagegencam` as the remote host.
9. Add `/home/imagegencam/Documents/imagegencam` as the project path.
10. Start the remote chat and send `Take over from here!`.

## Manual SSH Config

If the helper script is unavailable, add this to `~/.ssh/config` on the Mac:

```sshconfig
Host imagegencam
  HostName imagegencam.local
  User imagegencam
  IdentityFile ~/.ssh/imagegencam_ed25519
  IdentitiesOnly yes
```

Use the Pi IP for `HostName` if `.local` failed. Then create the dedicated key if needed and copy the local public key to the Pi:

```bash
test -f ~/.ssh/imagegencam_ed25519 || ssh-keygen -t ed25519 -f ~/.ssh/imagegencam_ed25519 -N "" -C imagegencam
cat ~/.ssh/imagegencam_ed25519.pub | ssh imagegencam@imagegencam.local 'umask 077; mkdir -p ~/.ssh; touch ~/.ssh/authorized_keys; key="$(cat)"; grep -qxF "$key" ~/.ssh/authorized_keys || printf "%s\n" "$key" >> ~/.ssh/authorized_keys'
```

After this, `ssh imagegencam` should connect without asking for the Pi password.

## Verify Remote Context

In remote Codex, run:

```bash
hostname
pwd
uname -a
command -v codex
```

Success looks like:

- `hostname` is `imagegencam`
- `pwd` is under `/home/imagegencam`
- `uname -a` reports Linux on Raspberry Pi hardware
- `command -v codex` returns a path

If commands run on the user's Mac, stop and reconnect Codex to the SSH host before installing packages or editing files.

## Common Failures

- `.local` does not resolve: use the router, hotspot client list, or `arp -a` to find the Pi IP.
- `codex` is missing on the Pi: connect with SSH first, then run the install block above in the Pi shell.
- SSH still asks for a password after setup: rerun `./scripts/setup_mac_ssh_to_pi.sh <pi-ip-address>` and confirm the final `ssh key ok` message.
- SSH alias points at an old IP: rerun `./scripts/setup_mac_ssh_to_pi.sh imagegencam.local`; the helper removes old exact `Host imagegencam` blocks before writing the new one.
- SSH host key changed after reflashing or reusing the same hostname: run `ssh-keygen -R imagegencam.local`, `ssh-keygen -R imagegencam`, and `ssh-keygen -R <pi-ip-address>`, then connect again.
- Password prompt blocks Codex: use `sudo-and-terminal.md` for a small Terminal handoff.

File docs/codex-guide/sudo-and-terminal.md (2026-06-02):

# Sudo And Terminal Handoff

Use this when a command needs `sudo`, asks for the Pi password, or blocks inside remote Codex.

## Rules

- Never ask the user to paste the Pi password into chat.
- Never ask the user to paste an OpenAI API key into chat.
- Never run password-prompting `sudo` commands in Codex's hidden tool terminal.
  The user cannot see or answer that prompt there.
- Do not use `sudo -S`.
- Keep Terminal handoff blocks short.
- After the user says the block is done, verify with read-only commands.

## Prebuilt Kit Password Change

If the user has a prebuilt kit, the first-boot screen may show a shared starter password. Have the user change it in a normal SSH Terminal session before API key setup:

```bash
ssh imagegencam@imagegencam.local
```

After the Pi shell prompt appears, run:

```bash
passwd
```

If `.local` failed, use the IP shown on the device screen:

```bash
ssh imagegencam@<pi-ip-address>
```

After the Pi shell prompt appears, run:

```bash
passwd
```

Tell the user the password input may look blank while they type. Do not ask them to paste either password into chat.

## Flow

1. Explain why admin access is needed.
2. Tell the user to open the **Terminal** app on their Mac.
3. Have them connect:

```bash
ssh imagegencam
```

4. Give only the small privileged block they need.
5. Ask them to come back and say whether it completed or share the error message with any passwords, tokens, or API keys removed.
6. Continue in remote Codex after verification.

## Example

For package install:

```bash
sudo apt update
sudo apt install -y git python3-venv python3-picamera2 python3-pil python3-pip network-manager nodejs npm
```

Verify afterward:

```bash
python3 -m venv --help >/dev/null && echo "venv ok"
rpicam-hello --list-cameras
```

## Prefer Verification Over Repetition

If a command may already have run on the prebuilt kit, check before reinstalling:

```bash
command -v rpicam-hello
python3 -c "import displayhatmini; print('displayhatmini ok')"
systemctl status pisugar-server --no-pager
```

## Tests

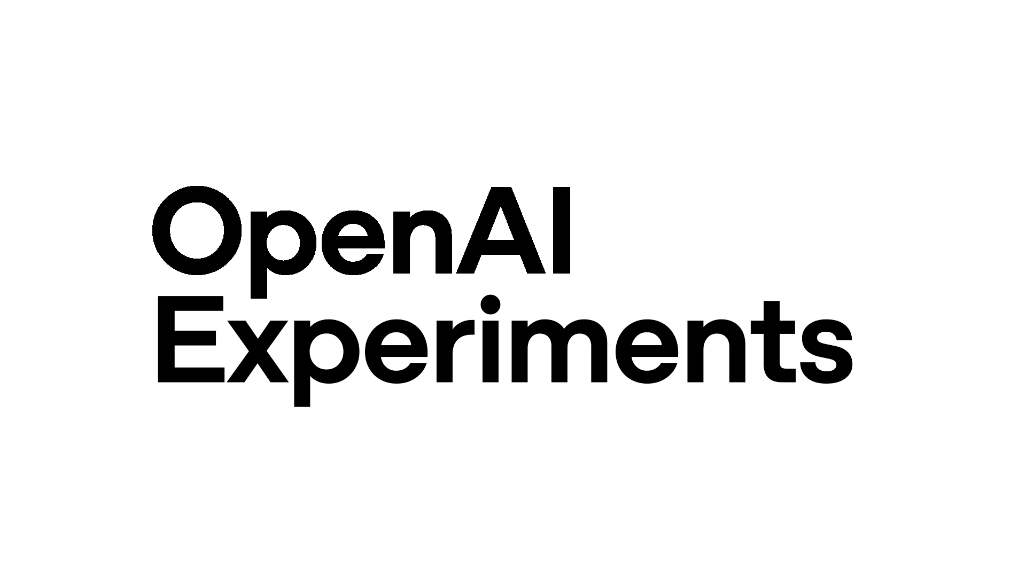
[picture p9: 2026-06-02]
assets/experiments-motion-sketch.gif

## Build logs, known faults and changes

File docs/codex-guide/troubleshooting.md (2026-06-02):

# Troubleshooting

Use this when something fails. Keep diagnostics small and specific.

## Service Health

Status:

```bash
sudo systemctl status imagegencam.service --no-pager
```

Recent logs:

```bash
sudo journalctl -u imagegencam.service -n 100 --no-pager
```

Follow logs:

```bash
sudo journalctl -u imagegencam.service -f
```

Stop while editing:

```bash
sudo systemctl stop imagegencam.service
```

## Camera App Crash Loop

If systemd repeatedly restarts the app, stop it first:

```bash
sudo systemctl stop imagegencam.service
```

Then check:

```bash
rpicam-hello --list-cameras
```

If Picamera2 logs `IndexError: list index out of range`, it usually means the camera stack sees no camera.

## Image Generation Fails

Check local config exists:

```bash
test -f ~/Documents/imagegencam/software/.env && echo ".env exists"
```

Check API key is set without printing it:

```bash
grep -q '^OPENAI_API_KEY=.' ~/Documents/imagegencam/software/.env && echo "API key present"
```

Check queue:

```bash
find ~/Documents/imagegencam/software/data/queue -type f | sort
```

Pending queue files mean work is preserved and should retry later.

## Web App Does Not Open

Check service:

```bash
sudo systemctl status imagegencam.service --no-pager
```

Check IP:

```bash
hostname -I
```

Check port:

```bash
ss -ltnp | grep -E ':(80|8000)' || true
```

Manual runs listen on port 8000. The installed service listens on port 80 so users can open `http://imagegencam.local`.

The web app is intentionally local-LAN only.

## Wi-Fi Change Failed

Do not delete saved connections while debugging. First list known profiles:

```bash
nmcli -t -f NAME,TYPE,AUTOCONNECT,DEVICE connection show
```

Show nearby Wi-Fi:

```bash
nmcli -t -f active,ssid,signal,security dev wifi list --rescan yes
```

Reconnect a known good profile:

```bash
sudo nmcli connection up id "PROFILE_NAME"
```

The on-device Wi-Fi selector schedules rollback before trying a new network. If the user does not press KEEP on the device, it should return to the previous active profile automatically.

If the display says activation failed and NetworkManager logs `Not authorized to control networking`, reinstall the service files:

```bash
cd ~/Documents/imagegencam/software
./scripts/install_service.sh
sudo systemctl restart imagegencam.service
```

That installs the narrow sudoers rule used for non-interactive Wi-Fi switching from the camera service.

## High CPU or Sluggish Preview

Check processes:

```bash
ps -eo pid,comm,args,%cpu,%mem --sort=-%cpu | head -20
```

Stop the app while editing:

```bash
sudo systemctl stop imagegencam.service
```

The Pi Zero 2 W is small. Avoid desktop, browser rendering, or extra services during camera use.

## Prompt/Web Data

Runtime data lives in:

```text
~/Documents/imagegencam/software/data
```

Do not commit personal runtime data unless the user intentionally wants it in the repo.

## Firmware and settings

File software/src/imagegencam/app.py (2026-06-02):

from __future__ import annotations

import logging
import os
from pathlib import Path

from .config import MagicHistoryStore, PromptStore, SettingsStore, load_env_file
from .controller import ImageGenCamController
from .job_store import PersistentJobStore
from .openai_client import OpenAIImageEditor, OpenAIMagicPromptPlanner
from .web import WebServerThread


def main() -> None:
    project_root = Path(__file__).resolve().parents[2]
    load_env_file(project_root / ".env")
    logging.basicConfig(
        level=os.environ.get("IMAGE_GEN_LOG_LEVEL", "INFO").upper(),
        format="%(asctime)s %(levelname)s %(name)s %(message)s",
    )

    host = os.environ.get("IMAGE_GEN_HOST", "0.0.0.0")
    port = int(os.environ.get("IMAGE_GEN_PORT", "8000"))
    model = os.environ.get("IMAGE_GEN_MODEL", "gpt-image-2")
    quality = os.environ.get("IMAGE_GEN_QUALITY", "low")
    size = os.environ.get("IMAGE_GEN_SIZE", "1536x1024")
    output_format = os.environ.get("IMAGE_GEN_OUTPUT_FORMAT", "jpeg")
    output_compression = int(os.environ.get("IMAGE_GEN_OUTPUT_COMPRESSION", "85"))
    timeout_seconds = float(os.environ.get("IMAGE_GEN_TIMEOUT_SECONDS", "90"))
    input_width = int(os.environ.get("IMAGE_GEN_INPUT_WIDTH", "1024"))
    input_height = int(os.environ.get("IMAGE_GEN_INPUT_HEIGHT", "768"))
    preview_width = int(os.environ.get("CAMERA_PREVIEW_WIDTH", "480"))
    preview_height = int(os.environ.get("CAMERA_PREVIEW_HEIGHT", "360"))
    frame_rate = int(os.environ.get("CAMERA_FRAME_RATE", "10"))

    prompt_store = PromptStore(project_root / "data" / "prompts.json")
    magic_history_store = MagicHistoryStore(project_root / "data" / "magic_history.json")
    settings_store = SettingsStore(project_root / "data" / "settings.json")
    generation_job_store = PersistentJobStore(project_root / "data" / "queue" / "generation")
    controller = ImageGenCamController(
        project_root=project_root,
        prompt_store=prompt_store,
        magic_history_store=magic_history_store,
        settings_store=settings_store,
        generation_job_store=generation_job_store,
        image_editor=OpenAIImageEditor(
            model=model,
            quality=quality,
            size=size,
            output_format=output_format,
            output_compression=output_compression,
            timeout_seconds=timeout_seconds,
        ),
        magic_prompt_planner=OpenAIMagicPromptPlanner(
            model=os.environ.get("MAGIC_MODE_MODEL", "gpt-4.1-mini"),
            timeout_seconds=float(os.environ.get("MAGIC_MODE_TIMEOUT_SECONDS", "30")),
        ),
        preview_size=(preview_width, preview_height),
        frame_rate=frame_rate,
        generation_input_size=(input_width, input_height),
    )
    web_server = WebServerThread(controller, host, port)
    web_server.start()

    try:
        controller.run()
    finally:
        web_server.stop()


if __name__ == "__main__":
    main()

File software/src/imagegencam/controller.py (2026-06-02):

from __future__ import annotations

"""Physical camera controller.

This module owns the hardware loop: camera frames, Display HAT Mini drawing,
button events, PiSugar shutter events, battery display, and background job
coordination. Pure storage/network helpers live in smaller modules so this file
can stay focused on device state.
"""

import json
import logging
import math
import os
import signal
import shutil
import socket
import subprocess
import time
from dataclasses import dataclass, field
from datetime import datetime
from io import BytesIO
from pathlib import Path
from queue import Empty, Queue
from threading import Lock, Thread
from urllib.parse import quote, unquote

from PIL import Image, ImageChops, ImageDraw, ImageFont, ImageOps
import qrcode

from .config import MagicHistoryStore, PromptStore, SettingsStore
from .job_store import PersistentJobStore
from .openai_client import OpenAIImageEditor, OpenAIImageError, OpenAIMagicPromptPlanner
from .wifi_manager import NetworkManagerWifi, WifiNetwork, WifiRollback


WIDTH = 320
HEIGHT = 240
SIDE_CONTROL_TOP_Y = 64
SIDE_CONTROL_BOTTOM_Y = HEIGHT - 98
PREVIEW_REDRAW_INTERVAL_SECONDS = 1.0 / 8.0
MENU_REDRAW_INTERVAL_SECONDS = 1.0 / 8.0
ALBUM_REDRAW_INTERVAL_SECONDS = 1.0 / 8.0
BATTERY_REFRESH_INTERVAL_SECONDS = 20.0
PISUGAR_POWER_BUTTON_POLL_INTERVAL_SECONDS = 0.02
PISUGAR_POWER_BUTTON_MAX_SHUTTER_PRESS_SECONDS = 0.6
QUEUE_RETRY_BASE_SECONDS = 15.0
QUEUE_RETRY_MAX_SECONDS = 15.0 * 60.0
FONT_PATH = str(Path(__file__).resolve().parents[2] / "assets" / "fonts" / "Orbitron-Regular.ttf")
MONO_FONT_PATH = FONT_PATH
SHUTTER_EVENT_DIR = Path("/tmp/imagegencam-shutter-events")
WIFI_KEYBOARD_CHARS = "abcdefghijklmnopqrstuvwxyzABCDEFGHIJKLMNOPQRSTUVWXYZ0123456789-_.!?#@$%&*/: "
logger = logging.getLogger(__name__)


@dataclass
class RuntimeState:
    mode: str = "preview"
    status_message: str = "Live camera preview"
    last_button: str | None = None
    last_error: str | None = None
    last_capture_path: str | None = None
    last_generated_path: str | None = None
    prompts: dict[str, str] = field(default_factory=dict)
    prompt_titles: dict[str, str] = field(default_factory=dict)
    current_prompt_button: str = "prompt-1"
    preview_calibration: dict[str, int] = field(default_factory=dict)
    capture_fps: str = "-"
    display_fps: str = "-"
    pending_jobs: int = 0
    ready_images: int = 0
    magic_mode_active: bool = False
    magic_prompt_title: str | None = None
    magic_prompt_ready: bool = False


@dataclass
class GenerationJob:
    prompt_button: str
    prompt_title: str
    prompt_body: str
    capture_path: Path
    generated_path: Path
    reference_paths: tuple[Path, ...] = ()
    magic_history_id: str | None = None


@dataclass
class CaptureRequest:
    prompt_button: str
    prompt_title: str
    prompt_body: str
    source_image: Image.Image
    reference_paths: tuple[Path, ...] = ()
    magic_history_id: str | None = None


@dataclass
class MagicSeedRequest:
    source_image: Image.Image


@dataclass
class MagicPromptState:
    history_id: str
    title: str
    body: str
    reference_capture_path: Path


class ImageGenCamController:
    def __init__(
        self,
        project_root: Path,
        prompt_store: PromptStore,
        magic_history_store: MagicHistoryStore,
        settings_store: SettingsStore,
        generation_job_store: PersistentJobStore,
        image_editor: OpenAIImageEditor,
        magic_prompt_planner: OpenAIMagicPromptPlanner,
        preview_size: tuple[int, int],
        frame_rate: int,
        generation_input_size: tuple[int, int],
    ) -> None:
        self.project_root = project_root
        self.prompt_store = prompt_store
        self.magic_history_store = magic_history_store
        self.settings_store = settings_store
        self.generation_job_store = generation_job_store
        self.image_editor = image_editor
        self.magic_prompt_planner = magic_prompt_planner
        self.preview_size = preview_size
        self.frame_rate = frame_rate
        self.generation_input_size = generation_input_size
        self.display_rotation = int(os.environ.get("DISPLAY_ST7789_ROTATION", "0"))
        self.web_port = int(os.environ.get("IMAGE_GEN_PORT", "8000"))
        self.camera_rotation_degrees = int(os.environ.get("CAMERA_ROTATION_DEGREES", "270"))
        self.capture_feedback_duration_seconds = max(
            0.05, float(os.environ.get("CAPTURE_FEEDBACK_DURATION_SECONDS", "0.25"))
        )
        self.max_pending_generations = max(0, int(os.environ.get("MAX_PENDING_GENERATIONS", "0")))
        self.capture_root = self.project_root / "data" / "captures"
        self.generated_root = self.project_root / "data" / "generated"
        self.capture_root.mkdir(parents=True, exist_ok=True)
        self.generated_root.mkdir(parents=True, exist_ok=True)
        settings = self.settings_store.load()
        self.app_background_theme = str(settings["app_background_theme"])
        self.camera_username = str(settings["camera_username"])

        self.swap_red_blue = os.environ.get("CAMERA_SWAP_RED_BLUE", "1").strip().lower() not in {
            "0",
            "false",
            "no",
        }
        self.stale_frame_timeout_seconds = float(
            os.environ.get("CAMERA_STALE_FRAME_TIMEOUT_SECONDS", "2.0")
        )
        self.magic_mode_enabled = os.environ.get("MAGIC_MODE_ENABLED", "1").strip().lower() not in {
            "0",
            "false",
            "no",
        }
        self.magic_history = self.magic_history_store.load_entries()
        self.magic_mode_active = False
        self.magic_prompt_pending = False
        self.current_magic_prompt: MagicPromptState | None = self._load_latest_magic_prompt()

        self.prompt_entries = self.prompt_store.load_entries()
        self.prompt_order = tuple(self.prompt_entries.keys())
        self.selected_prompt_index = 0
        self.prompt_picker_index = 0
        initial_prompt_id = self.prompt_order[0]
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
